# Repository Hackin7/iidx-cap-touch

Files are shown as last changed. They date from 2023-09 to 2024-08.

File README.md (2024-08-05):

# iidx-cap-touch
Beatmania IIDX Capacitive Touch Controller

## PCB 2

pcb2

pcb2

Usage
1. Connect 1 MPR121 to a RPi Pico
    - Can extend with an additional MPR121 port
2. Top left (thin) pad can act as turntable button - Or you can use PCB 1 with an additional MPR121 for a turntable
3. CircuitPython on the RPi Pico allows you to configure keybindings
4. Should Tapedown the controller to prevent sliding - cap touch + pcb + tapedown = minimal noise

Ordering
1. Both PCBs in the picture are using the same design - Can order 1 pack of 5 for $2 + $2 for 2 weeks shipping
2. Connect them together through headers/ wires

## PCB 1

1. Connect 2 MPR121 to a Raspberry Pi Pico, each on different I2C buses
2. CircuitPython Code to simulate a turntable (still a bit wonky, but usable for simple maps)
3. PCB controller for ease of use. 5 costs $2 + $2 shipping in 10 days or so.

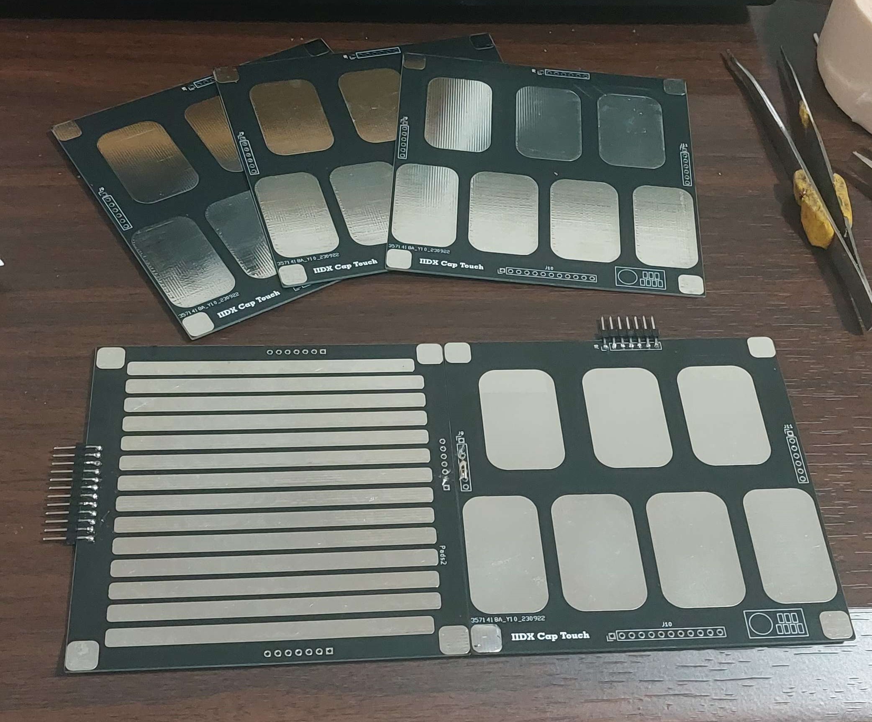
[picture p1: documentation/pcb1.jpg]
pcb


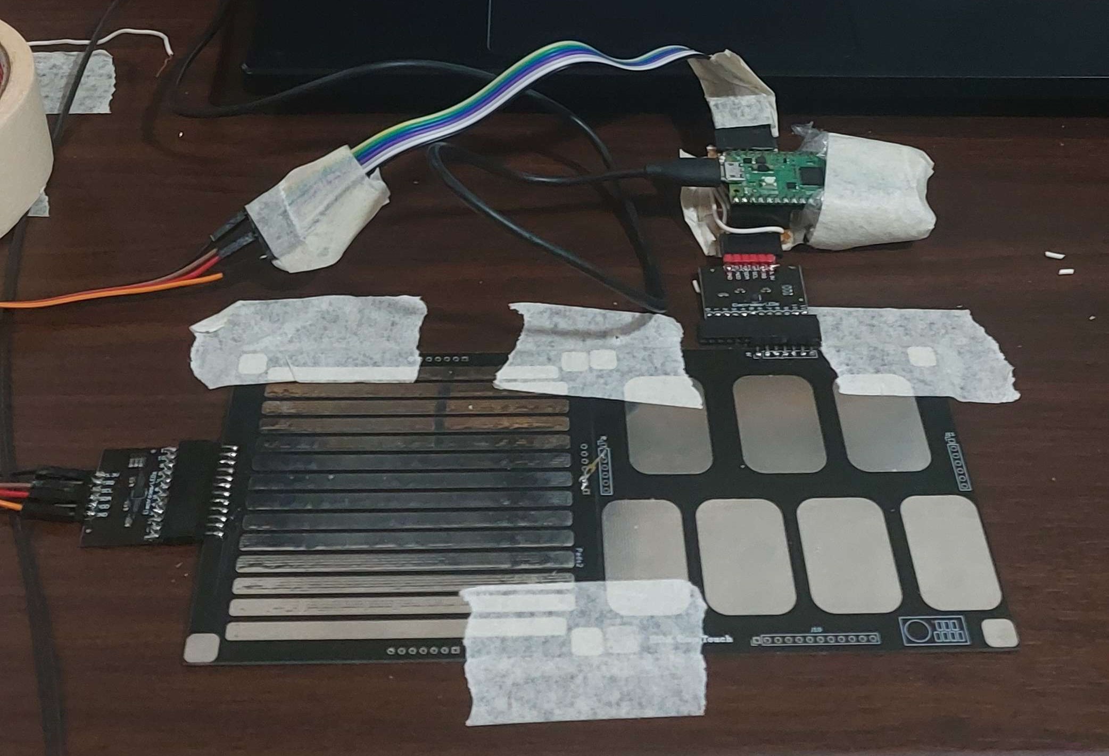
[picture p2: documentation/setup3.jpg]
setup


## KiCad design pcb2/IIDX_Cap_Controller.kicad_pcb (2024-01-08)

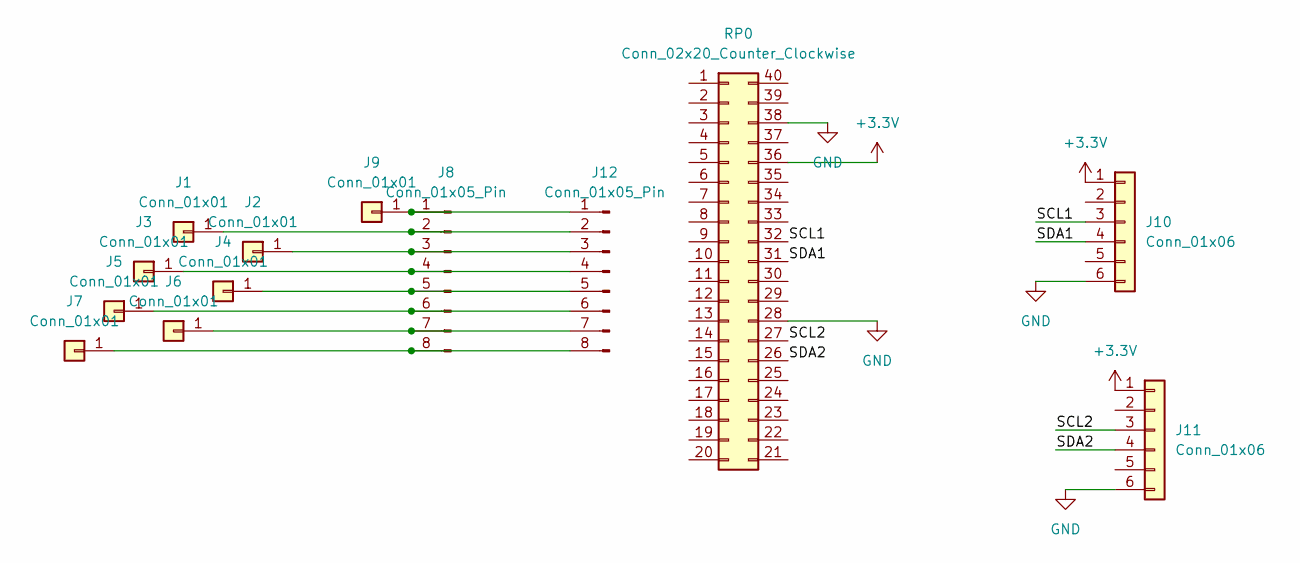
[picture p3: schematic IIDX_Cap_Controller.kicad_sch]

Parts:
J1, J2, J3, J4, J5, J6, J7, J9: Conn_01x01; 4807e8d7-bff8-4c85-8422-397af0b06065
J8: Conn_01x05_Pin; PinHeader_1x08_P2.54mm_Vertical
J10: Conn_01x06; PinHeader_1x06_P2.54mm_Vertical
J11: Conn_01x06
J12: Conn_01x05_Pin; PinHeader_1x08_P2.54mm_Vertical_SMD_Pin1Left
RP0: Conn_02x20_Counter_Clockwise

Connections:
+3.3V: J10.1, J11.1, RP0.36
/SCL1: J10.3, RP0.32
/SCL2: J11.3, RP0.27
/SDA1: J10.4, RP0.31
/SDA2: J11.4, RP0.26
GND: J10.6, J11.6, RP0.28, RP0.38
unnamed: J1.1, J8.2, J12.2
unnamed: J8.1, J9.1, J12.1
unnamed: J2.1, J8.3, J12.3
unnamed: J3.1, J8.4, J12.4
unnamed: J4.1, J8.5, J12.5
unnamed: J5.1, J8.6, J12.6
unnamed 12: J6.1, J8.7, J12.7; also elsewhere on the board
unnamed: J7.1, J8.8, J12.8

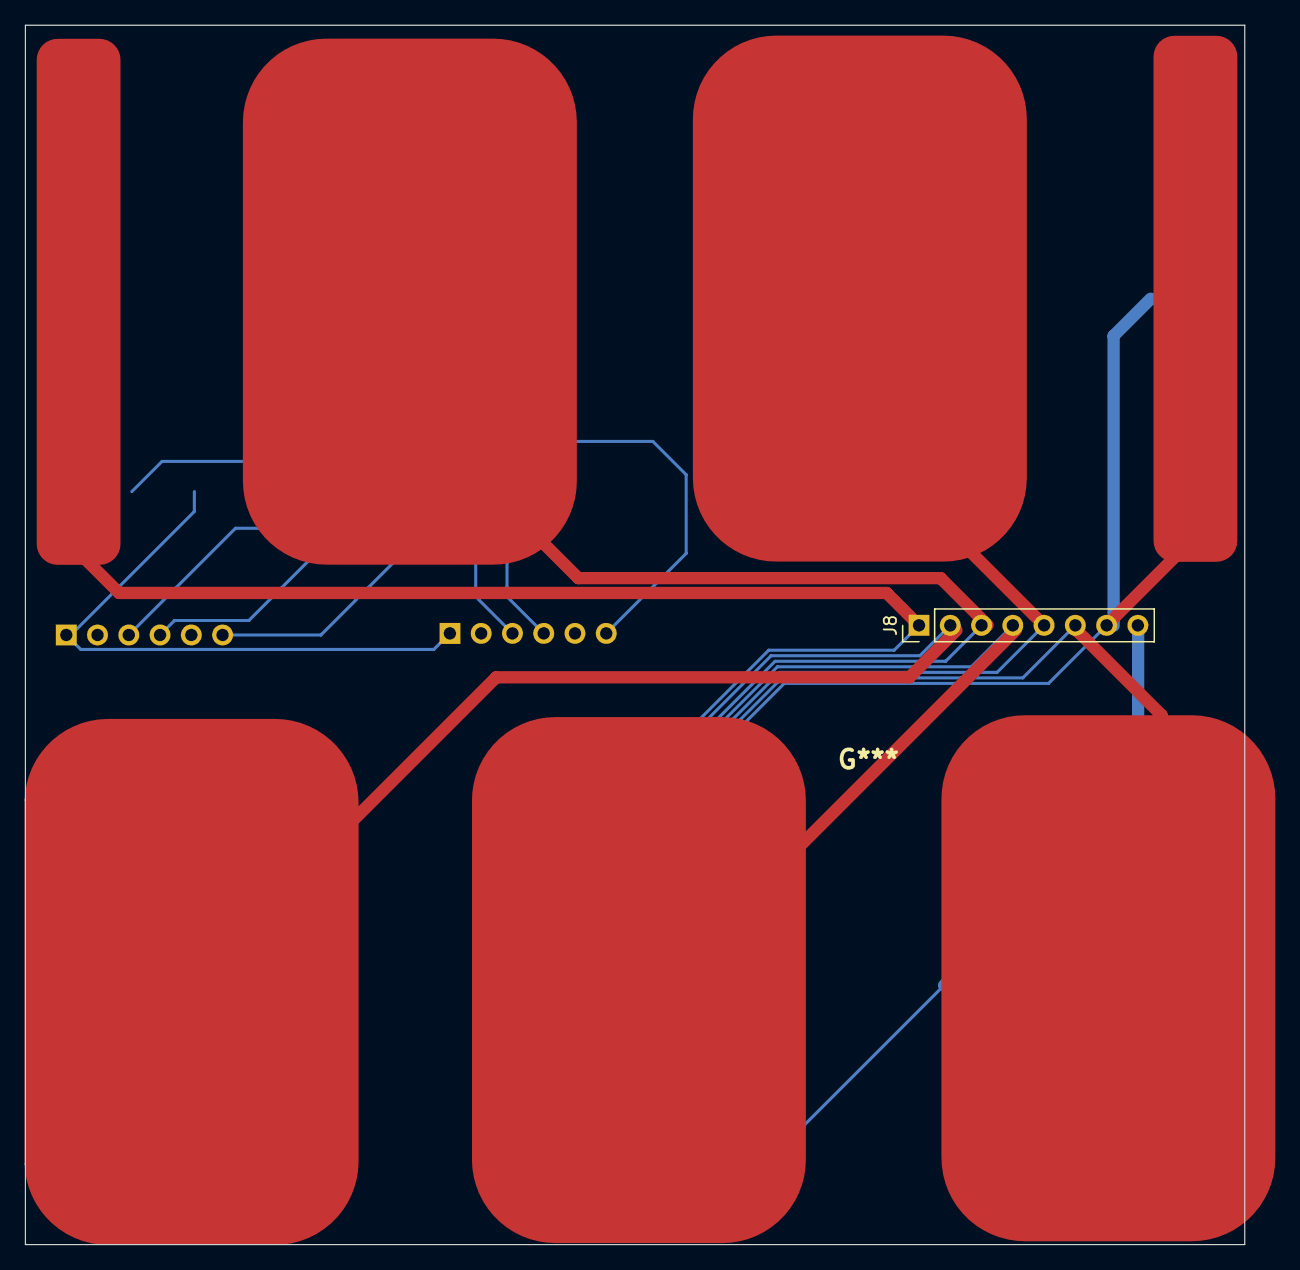
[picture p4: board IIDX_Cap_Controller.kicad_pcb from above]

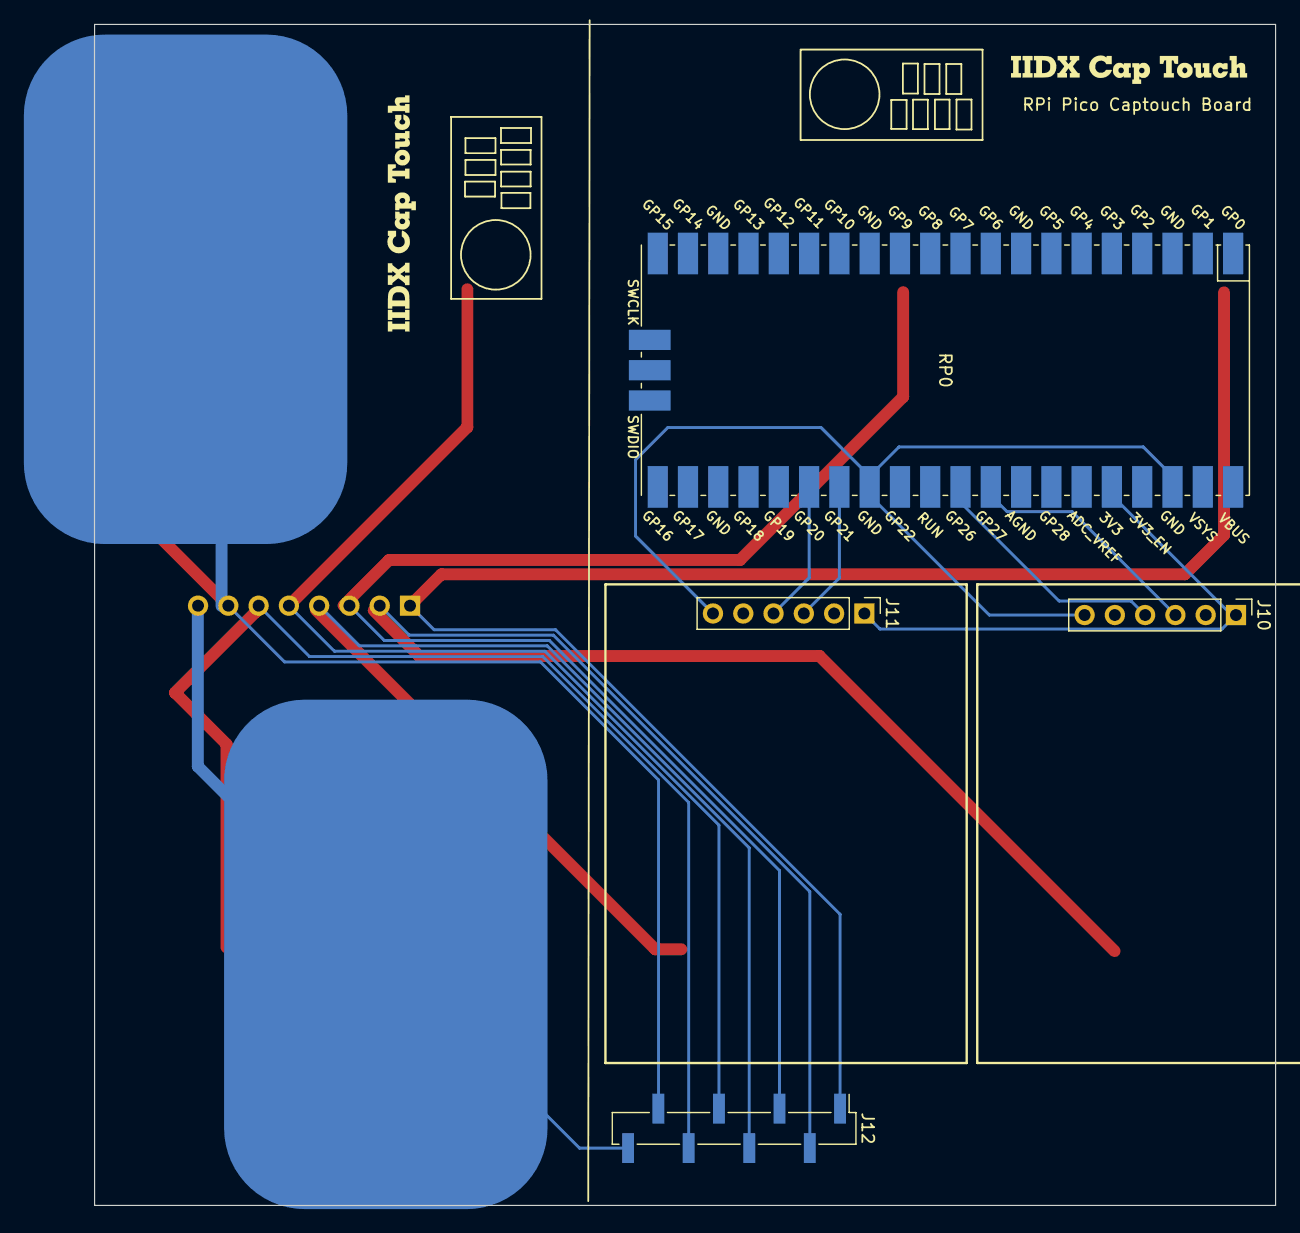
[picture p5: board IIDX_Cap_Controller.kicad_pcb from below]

Board: 2 copper layers, 99.1 x 99.1 mm, 14 parts (6 on the bottom side), 14 nets.

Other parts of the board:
J6#2: Conn_01x01; 4807e8d7-bff8-4c85-8422-397af0b06065

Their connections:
unnamed 12: J6#2.1; also elsewhere on the board

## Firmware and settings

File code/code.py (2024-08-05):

'''
# SPDX-FileCopyrightText: 2017 Limor Fried for Adafruit Industries
# 
# SPDX-License-Identifier: MIT
# If you run this and it seems to hang, try manually unlocking
# your I2C bus from the REPL with
#  >>> import board
#  >>> board.I2C().unlock()

import time
import busio
import board
i2c = busio.I2C(scl=board.GP1, sda=board.GP0)

while not i2c.try_lock():
    pass

try:
    while True:
        print(
            "I2C addresses found:",
            [hex(device_address) for device_address in i2c.scan()],
        )
        time.sleep(2)

finally:  # unlock the i2c bus when ctrl-c'ing out of the loop
    i2c.unlock()
'''
print("Hello World!")
import time
import board
import busio

import digitalio
import usb_hid
from adafruit_hid.keyboard import Keyboard
from adafruit_hid.keyboard_layout_us import KeyboardLayoutUS
from adafruit_hid.keycode import Keycode
from adafruit_hid.mouse import Mouse
import adafruit_mpr121
import time


keycodes = ([Keycode.F,Keycode.T,Keycode.G,Keycode.Y,Keycode.H,Keycode.U,Keycode.J][::-1] + [Keycode.A, Keycode.F, Keycode.F] +  [Keycode.Z, Keycode.X])
key_prev_value = [False for i in range(len(keycodes))]


#i2c = busio.I2C(scl=board.GP3, sda=board.GP2)
i2c = busio.I2C(scl=board.GP21, sda=board.GP20)
#i2c = busio.I2C(board.SCL1, board.SDA1)
keyboard = Keyboard(usb_hid.devices)
keyboard_layout = KeyboardLayoutUS(keyboard)  # We're in the US :)
mpr121 = adafruit_mpr121.MPR121(i2c)#, address=0x5c)

mouse = Mouse(usb_hid.devices)
#i2c1 = busio.I2C(scl=board.GP1, sda=board.GP0)
#mpr121_turntable = adafruit_mpr121.MPR121(i2c1)#, address=0x5c)
turntable_count = 0
turntable_last_pressed = time.monotonic()

turntable_prev_value = [False for i in range(len(keycodes))]
turntable_pins = [2, 3, 4]
def run():
    prev_key = None
    prev_turntable = 0
    turntable_last_pressed = time.monotonic()
    while True:
        for i in range(len(keycodes)):
            if mpr121[i].value == key_prev_value[i]:
                continue
            key_prev_value[i] = mpr121[i].value
            if mpr121[i].value:
                print(f"Pin {i} touched!")
                ### Turntable Code #####################################
                '''
                if keycodes[i] == Keycode.A and prev_turntable != i:
                    ### is sliding across
                    if -1 <= prev_turntable - i < 0: # Going Up
                        for i in range(12):
                            keyboard.press(Keycode.UP_ARROW)
                            time.sleep(0.001)
                            keyboard.release(Keycode.UP_ARROW)
                        print("Up")
                    elif 0 < prev_turntable - i <= 1: # Going Down
                        for i in range(12):
                            keyboard.press(Keycode.DOWN_ARROW)
                            time.sleep(0.001)
                            keyboard.release(Keycode.DOWN_ARROW)
                        print("Down")
                    else: # Reset Position
                        pass
                    #keyboard.press(keycodes[i])
                    print(prev_turntable, i, prev_turntable - i)
                    prev_turntable = i
                    continue
                elif keycodes[i] == Keycode.A:
                    prev_turntable = i
                    continue
                '''
                ########################################################
                keyboard.press(keycodes[i])
                prev_key = keycodes[i]
            else:
                keyboard.release(keycodes[i])
                prev_key = keycodes[i]
        #time.sleep(0.01)
        '''
        for i in range(len(keycodes)):
            if mpr121_turntable[i].value == turntable_prev_value[i]:
                continue
            turntable_prev_value[i] = mpr121_turntable[i].value
            if mpr121_turntable[i].value:
                print(f"Turntable Pin {i} touched!")
                ### Turntable Code #####################################
                if time.monotonic() - turntable_last_pressed > 2:
                    #print("trigger reset")
                    #turntable_last_pressed = time.monotonic()
                    #prev_turntable = i
                    #continue
                    pass
                turntable_last_pressed = time.monotonic()
                if prev_turntable != -1 and prev_turntable != i:
                    if 1 <= prev_turntable - i <= 2:
                        print("mouse down")
                        mouse.move(y=50)
                        #keyboard.press(Keycode.DOWN_ARROW)
                    elif -2 <= prev_turntable - i <= -1:
                        print("mouse up")
                        mouse.move(y=-50)
                        #keyboard.press(Keycode.UP_ARROW)
                    #print(f"prev {prev_turntable} touched!")

                ########################################################
                prev_turntable = i
            else:
                pass
                #keyboard.release(keycodes[i])
                #prev_turntable = -1

        '''
while True:
    try:
        run()
    except Exception as e:
        print(e)
#'''

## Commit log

2023-09-30 feat: base commit
    [IIDX_Cap_Controller.kicad_pcb, IIDX_Cap_Controller.kicad_sch]
2023-09-30 chore: cleanup
    [IIDX_Cap_Controller.kicad_pcb, IIDX_Cap_Controller.kicad_sch]
2024-01-04 feat: pcb2 rough layout
    [IIDX_Cap_Controller.kicad_pcb, IIDX_Cap_Controller.kicad_sch]
2024-01-05 feat: layout & routing with pico onboard
    [IIDX_Cap_Controller.kicad_pcb, IIDX_Cap_Controller.kicad_sch]
2024-01-08 feat: production 2
    [IIDX_Cap_Controller-B_Cu.gbr, IIDX_Cap_Controller-B_Mask.gbr, IIDX_Cap_Controller-B_Paste.gbr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]
